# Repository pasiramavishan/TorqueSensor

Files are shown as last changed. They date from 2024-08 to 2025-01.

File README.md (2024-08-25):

# Torque-Sensor

## Power Supply

In our battery-powered setup, we utilize a regulator circuit to maintain stable voltage output, ensuring consistent power supply to both the microcontroller and strain gauges. We selected BD450M5 due to its low dropout voltage, which is typically 0.2V. Its maximum current rating is 0.5A.

<p align="center">
  Power
</p>

## Bridge Balancing Circuit
 
The initial unbalances in strain gauge circuits, caused by irregularities in gauge resistances, often exceed the actual strain-induced signal. The solution involves adjusting resistances within the Wheatstone Bridge configuration. However, manual methods pose challenges such as determining the arm needing adjustment and avoiding further imbalance.

<p align="center">
  Power
</p>

We choosed AD5171 as the digital potentiometer to adjust resistance because,
 - Stores the resistance value, maintaining the wiper position even when power is off and resuming it when power is restored.
 - Permanently stores a chosen resistance value after OTP activation.
 - Allows unlimited adjustments to the resistor value prior to OTP activation.
 - 64 The AD5171 has 64 discrete wiper positions.
 - This fine adjustment allows for precise control over the resistance settings.

 ## Instrumentation Amplifier Circuit
 
To enhance the output signal from a Wheatstone bridge, we employ an instrumentation amplifier, known for its precision in measurement applications. Specifically, we’ve chosen the AD8293G160 for its cost effectiveness and capability to amplify the signal without introducing significant noise. This amplifier maintains accuracy over time and operates efficiently with minimal power requirements. In addition, we have refined the signal further by incorporating filters to eliminate unwanted noise, ensuring a clean and reliable output for our measurement purposes. The circuit amplifies the voltage difference between the Wheatstone bridge strain gauge. 

<p align="center">
  Power
</p>

Here why we used AD8293G160.
 - Up to 160 MHz, suitable for high-speed signal processing.
 - Typically 20 µV offset voltage and 0.3 µV/°C drift, minimizing signal processing errors.
 - Typically 140 dB CMR, effective in rejecting common-mode noise.
 - Includes overvoltage protection and thermal shutdown for reliable operation.
 - The amplifier has a gain of 160, which is suitable for our application.

## Offset Circuit for Instrumentation Amplifier
 
The combination of an instrumentation amplifier, such as the AD8293G160, with a digital-to-analog converter (DAC) like the MCP4728, offers precise offset adjustment capabilities in electronic circuits. The instrumentation amplifier serves to accurately amplify small differential signals while rejecting common-mode noise. However, in some applications, it’s necessary to introduce an offset voltage to bias the amplifier’s output to a specific level or compensate for certain system characteristics. By integrating a DAC into the circuit, engineers can dynamically adjust this offset voltage digitally. The MCP4728 provides multiple channels of analog output with high resolution, typically through an I2C interface. This allows for precise control over the offset voltage applied to the instrumentation amplifier.

<p align="center">
  Power
</p>

Here’s why we used MCP4728 over other DACs.
 - Provides up to 12-bit resolution for precise analog signal representation.
 - Designed for efficient power usage, beneficial for battery-powered applications.
 - Offers low noise, high linearity, and reliable operation in various conditions.
 - Includes on-board nonvolatile memory (EEPROM) for storing DAC codes and configuration settings

### Amplifier Circuit
 
To amplify the weak signal from the instrumentation amplifier, the circuit incorporates a secondary amplifier, the OPA336, which operates efficiently on low supply voltage and features a rail-to-rail output swing. Configured as a non-inverted amplifier with a single-pole low-pass filter, it ensures signal flexibility across different force ranges. Gain adjustments are made using the AD5171 digital potentiometer, which provides precise control with 64-step resolution for optimal signal amplification.

<p align="center">
  Power
</p>

Here are the advantages of the OPA336 operational amplifier (op-amp) compared to other typical op-amps like the LM741 and TL072.
 - Very low power consumption, ideal for battery-operated devices.
 - High speed (up to 10 MHz bandwidth) and precision with low offset voltage.
 - Low noise density and distortion, suitable for sensitive measurement.
 - Designed for efficient single-supply operation.

###  Microcontroller Circuit
 
The microcontroller is used both to display the output torque value and to act as the ADC converter. The unit converts the analog signal from the strain gauges into digital data, acting as an ADC, calculates the corresponding torque value, and controls the output signal, which may involve displaying the torque value or transmitting it to external devices. The ADC converts the analog input signal into a 10-bit digital value, providing 1024 discrete levels of representation.

<p align="center">
  Power
</p>

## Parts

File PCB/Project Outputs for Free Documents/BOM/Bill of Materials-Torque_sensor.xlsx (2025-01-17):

Comment | Description | Designator | Footprint | LibRef | Quantity
0.1uF | CAP CER 0.1UF 25V C0G/NP0 1206 | C1, C3, C7, C9, C11, C12, C15, C17, C22 | FP-C1206C-EB-MFG | CMP-1037-04186-2 | 9
12063C224JAT2A | Capacitor | C2, C4 | CAPC3216X94N | 12063C224JAT2A | 2
12065C474JAT2A | Capacitor | C5 | CAPC3216X152N | 12065C474JAT2A | 1
12063C334MAT2A | Capacitor | C6, C10, C13 | CAPC3216X127N | 12063C334MAT2A | 3
12063A4R7DAT2A | Capacitor | C8 | CAPC3216X94N | 12063A4R7DAT2A | 1
CGA5L1X7R1C106K160AC | Capacitor | C14, C16 | CAPC3216X190N | CGA5L1X7R1C106K160AC | 2
12063A220JAT2A | Capacitor | C18, C19 | CAPC3216X94N | 12063A220JAT2A | 2
12063C105MAT2A | Capacitor | C20 | CAPC3216X178N | 12063C105MAT2A | 1
12063D226MAT2A | Capacitor | C21 | CAPC3216X229N | 12063D226MAT2A | 1
OPA336NA_3K | Integrated Circuit | IC1 | SOT95P280X145-5N | OPA336NA_3K | 1
BD450M5FP-CE2 | Integrated Circuit | IC2 | ROHM_TO-252-3 | BD450M5FP-CE2 | 1
MCP4728-E_UN | Integrated Circuit | IC3 | SOP50P490X110-10N | MCP4728-E_UN | 1
B4B-XH-A(LF)(SN) | CONN HEADER VERT 4POS 2.5MM | J1, J4 | FP-B4B-XH-A_LF_SN-MFG | CMP-17439-000250-1 | 2
M20-9990246 | CONN HEADER VERT 2POS 2.54MM | J2, J3 | FP-M20-9990246-MFG | CMP-15831-000009-1 | 2
87914-0606 | Connector | J5 | HDRV6W69P254_2X3_762X498X859P | 87914-0606 | 1
B2B-XH-A(LF)(SN) | CONN HEADER VERT 2POS 2.5MM | J6 | FP-B2B-XH-A_LF_SN-MFG | CMP-2000-05888-3 | 1
B3B-XH-A(LF)(SN) | CONN HEADER VERT 3POS 2.5MM | J7 | FP-B3B-XH-A_LF_SN-MFG | CMP-17439-000014-3 | 1
ERA-8AEB103V | Resistor | R1, R3, R6, R7, R9 | RESC3216X70N | ERA-8AEB103V | 5
CHP1206AFX-4701ELF | Resistor | R2, R4 | RESC3116X65N | CHP1206AFX-4701ELF | 2
ERA8AEB102V | Resistor | R5 | RESC3216X70N | ERA8AEB102V | 1
ERA-8AEB272V | Resistor | R8 | RESC3216X70N | ERA-8AEB272V | 1
TS-1187A-B-A-B | Switch | S1 | TS1187ABAB | TS-1187A-B-A-B | 1
AD5171BRJZ100-R2 | AD5171BRJZ100-R2 Digital Potentiometer 64POS 100kOhm Single Automotive 8-Pin SOT-23 T/R | U1, U3 | FP-RJ-8-IPC_A | CMP-00026-00446399-1 | 2
AD8293G160ARJZ-R7 | IC INST AMP 1 CIRCUIT SOT23-8 | U2 | FP-RJ-8-IPC_B | CMP-09116-000116-1 | 1
ATmega328P-AU | 8-bit AVR Microcontroller, 32KB Flash, 1KB EEPROM, 2KB SRAM, 32-pin TQFP, Industrial Grade (-40°C to 85°C) | U4 | 32A_M | CMP-0095-00269-2 | 1
CX3225SA40000D0PTWCC | Crystal or Oscillator | Y1 | CX3225SA40000D0PTWCC | CX3225SA40000D0PTWCC | 1

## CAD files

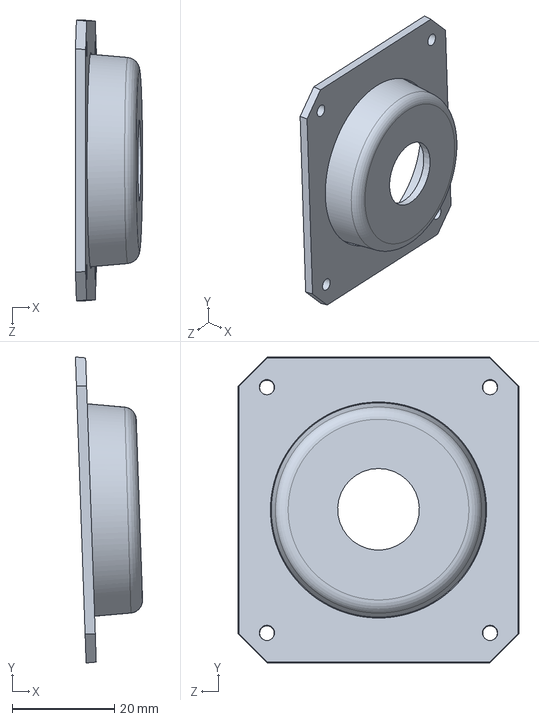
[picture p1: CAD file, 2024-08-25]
Enclosure/Side_Part.SLDPRT
13.2 x 60.0 x 55.0 mm

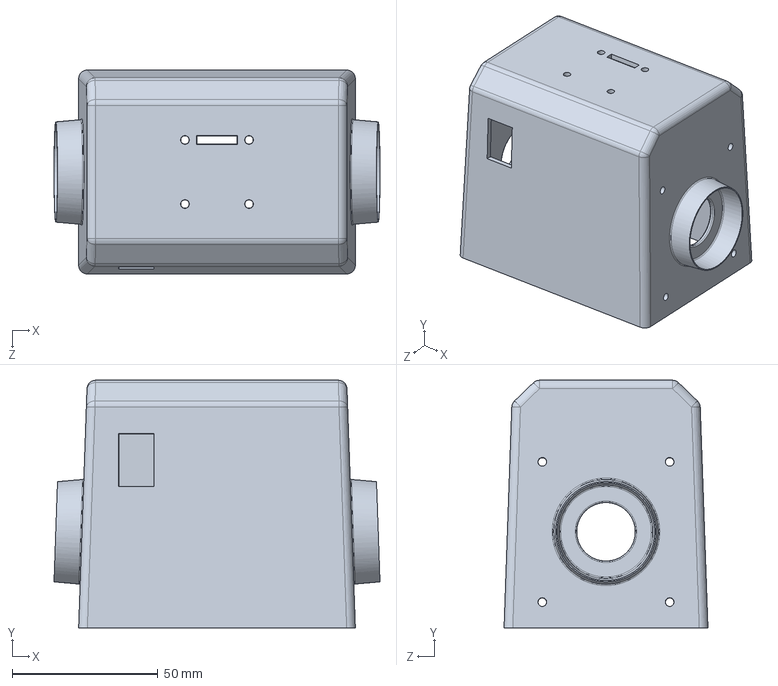
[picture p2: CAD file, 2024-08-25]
Enclosure/Top_Part.SLDPRT
111.9 x 85.0 x 70.0 mm

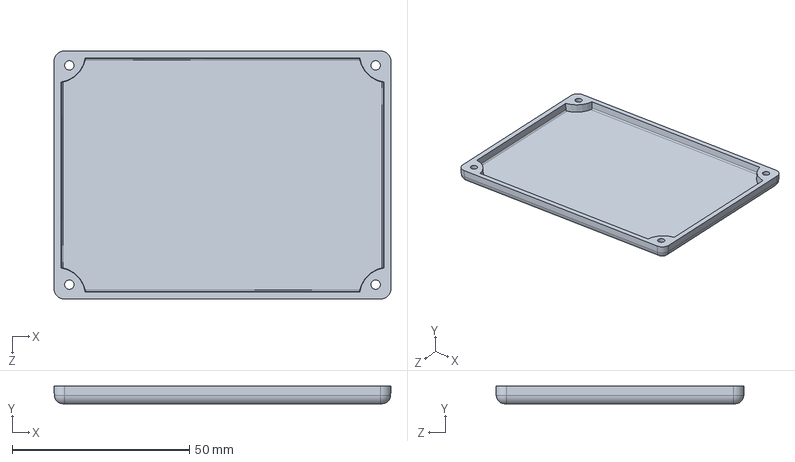
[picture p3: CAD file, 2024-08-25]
Enclosure/Bottom_Part.SLDPRT
95.0 x 5.00 x 70.0 mm

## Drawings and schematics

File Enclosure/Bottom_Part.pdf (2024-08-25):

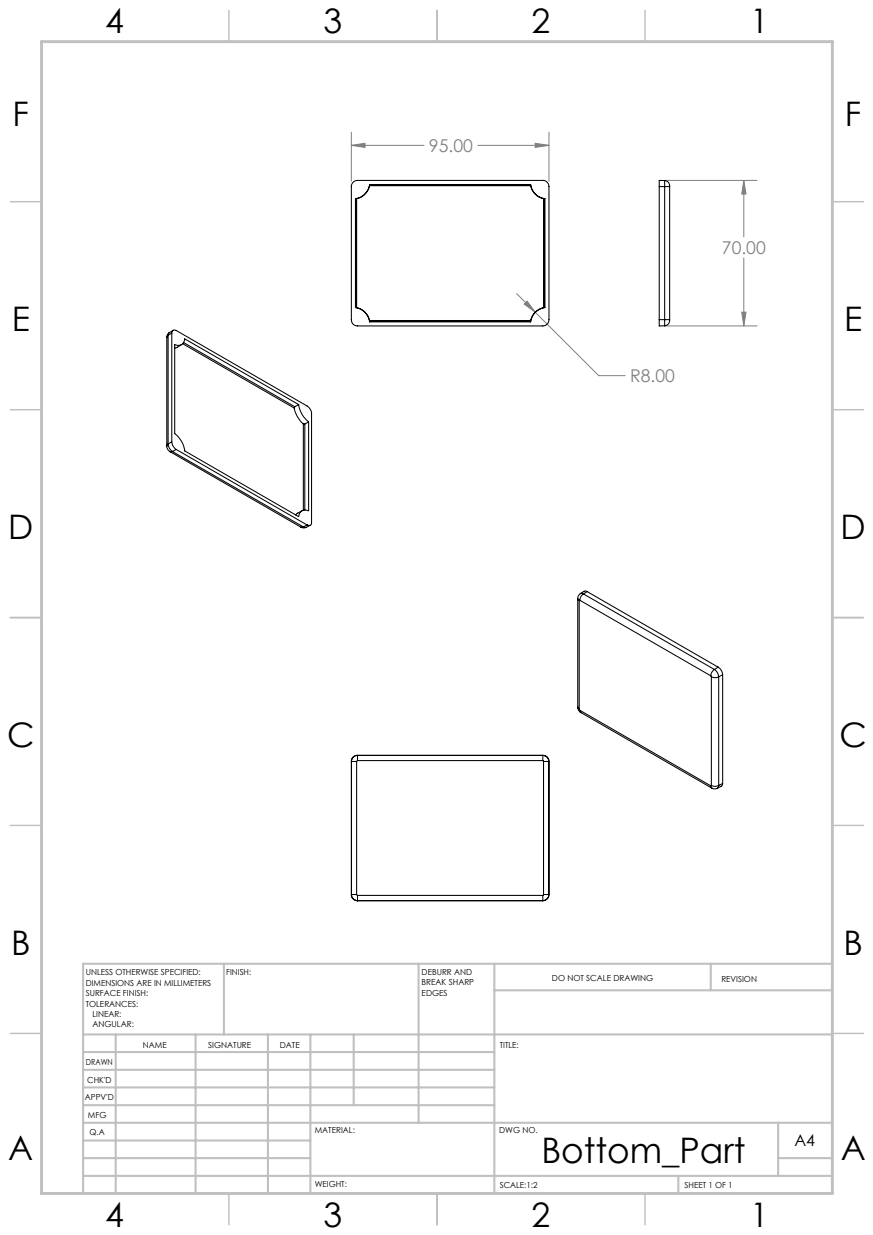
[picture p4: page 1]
FINISH:; DEBURR AND; BREAK SHARP; DO NOT SCALE DRAWING; REVISION; SCALE:1:2; SHEET 1 OF 1

UNLESS OTHERWISE SPECIFIED:
DIMENSIONS ARE IN MILLIMETERS
SURFACE FINISH:
TOLERANCES:
LINEAR:
ANGULAR:

NAME | SIGNATURE | DATE | | | | TITLE:

DRAWN
CHK'D
APPV'D
MFG
Q.A | | | | MATERIAL: | DWG NO. Bottom_Part | A4

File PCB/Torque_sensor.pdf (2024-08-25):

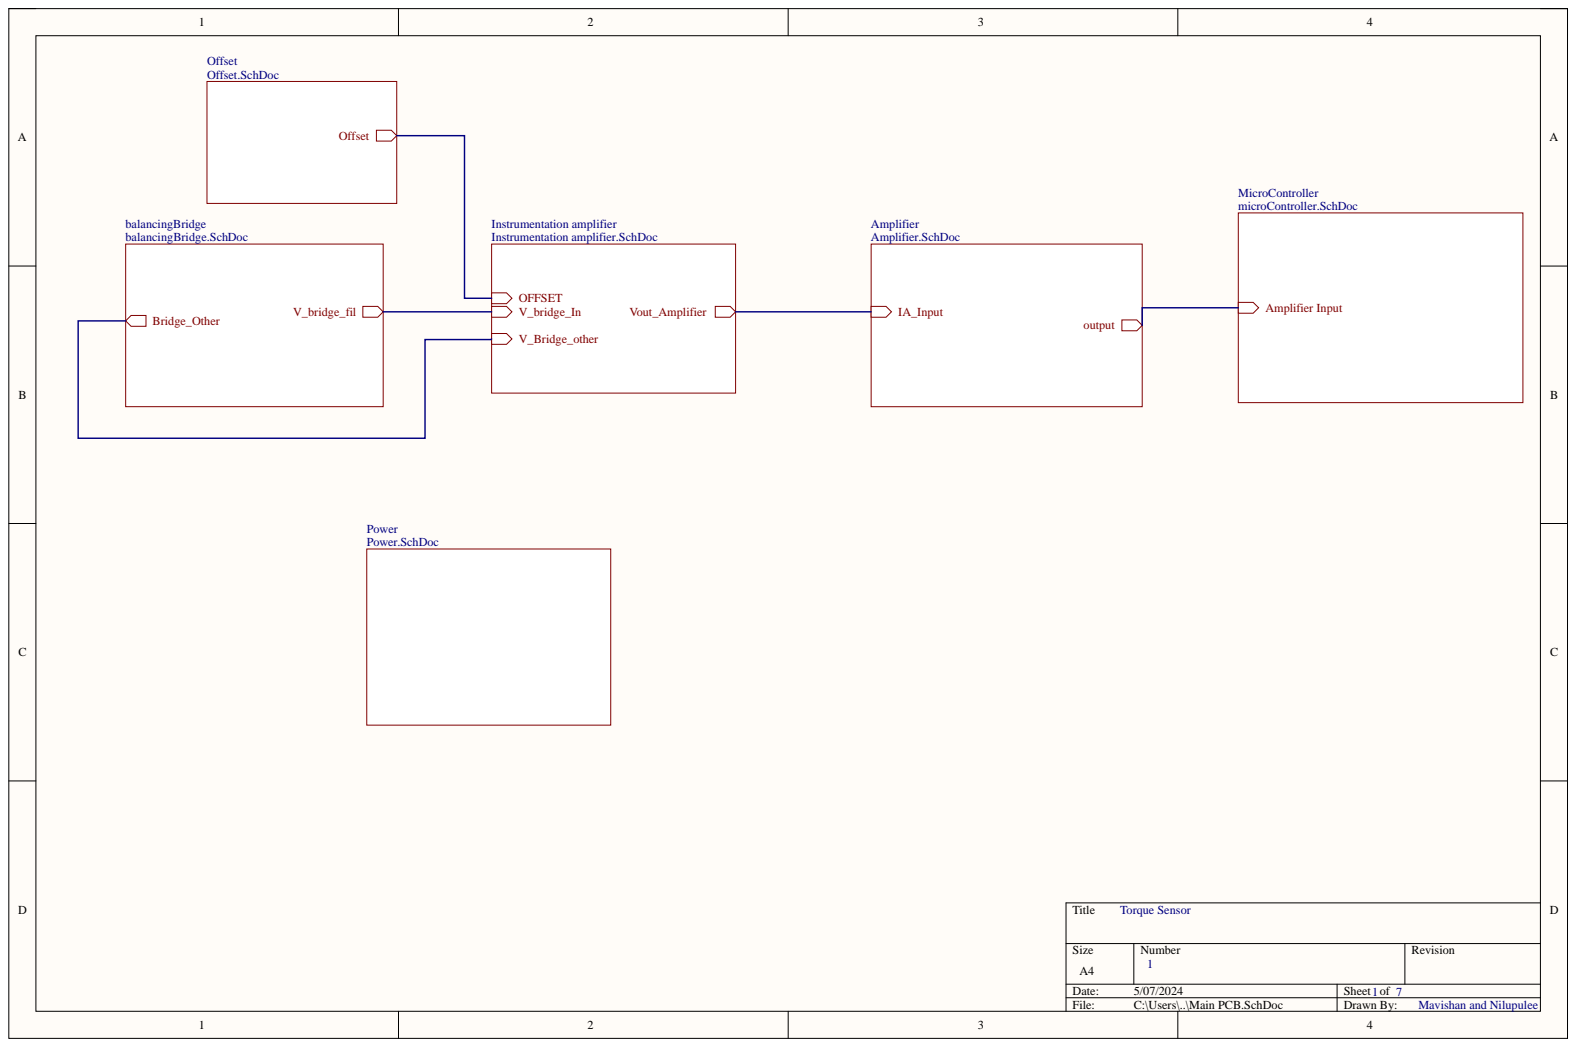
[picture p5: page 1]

Size A4 | Number 1 | Revision

Date: 5/07/2024 | Sheet of 1 7
File: C:\Users\..\Main PCB.SchDoc | Drawn By: Mavishan and Nilupulee

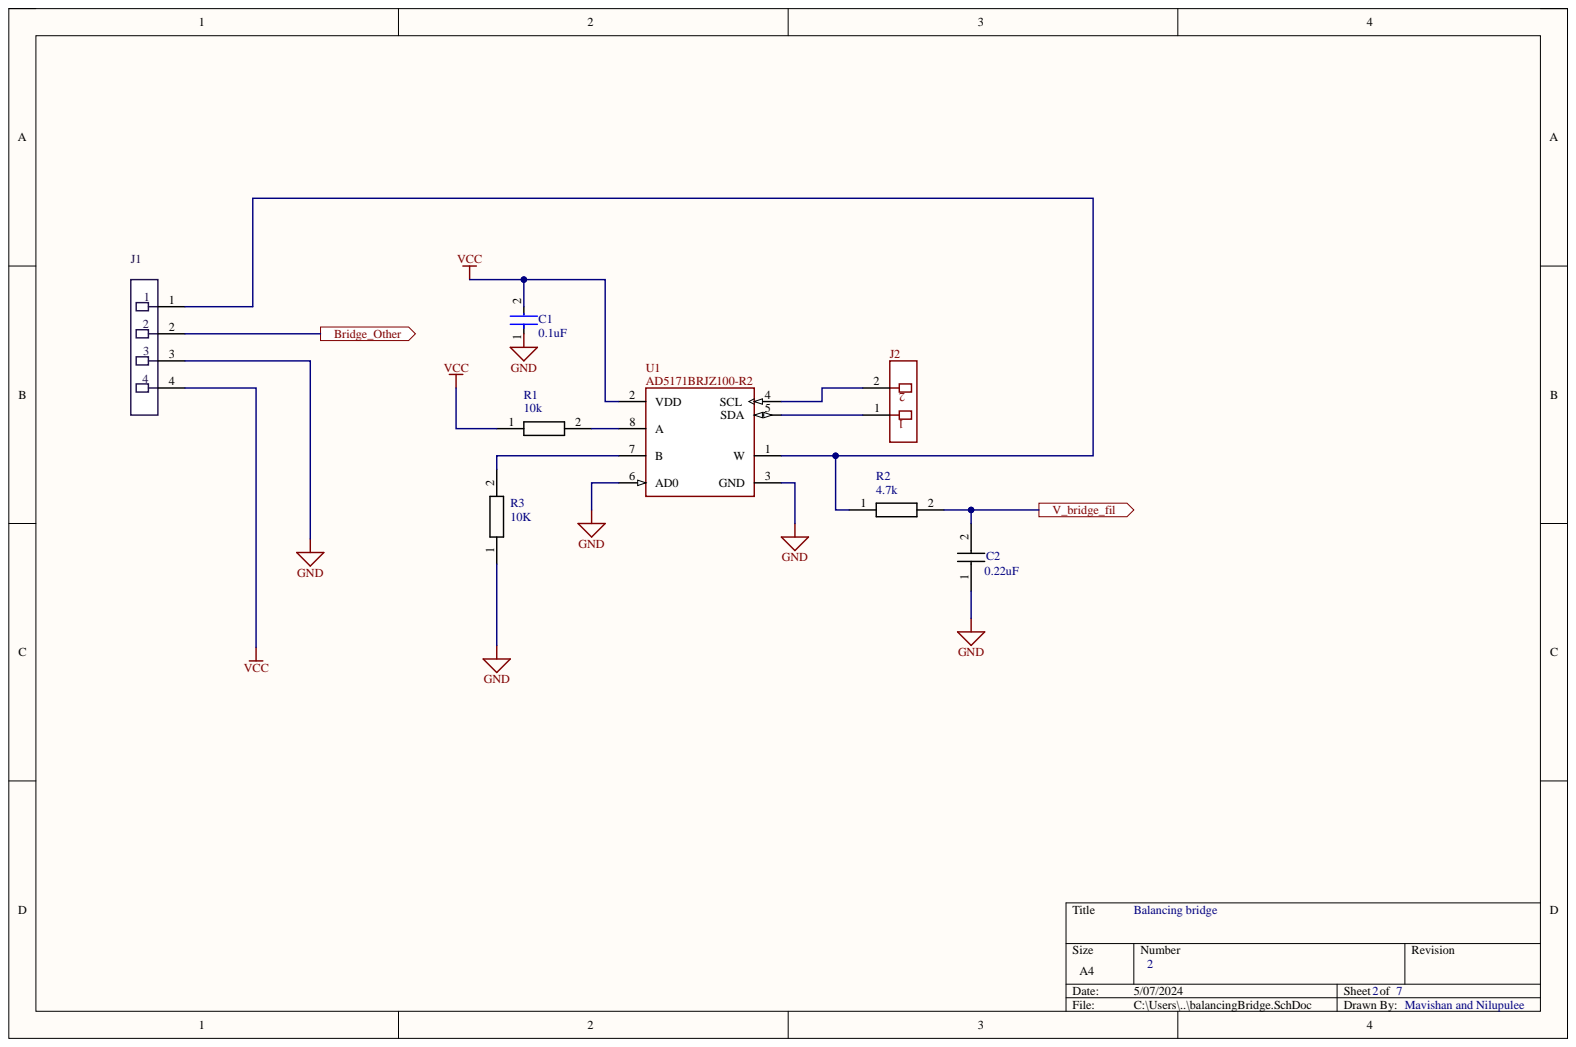
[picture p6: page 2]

GND | C1

Size A 4 | Numbe r 2 | Revision

Date: 5/07/2024 | Sheet of 2 7
File: C:\Users\..\balancingBridge. S chDoc | Drawn By: Mavishan and Nilupulee

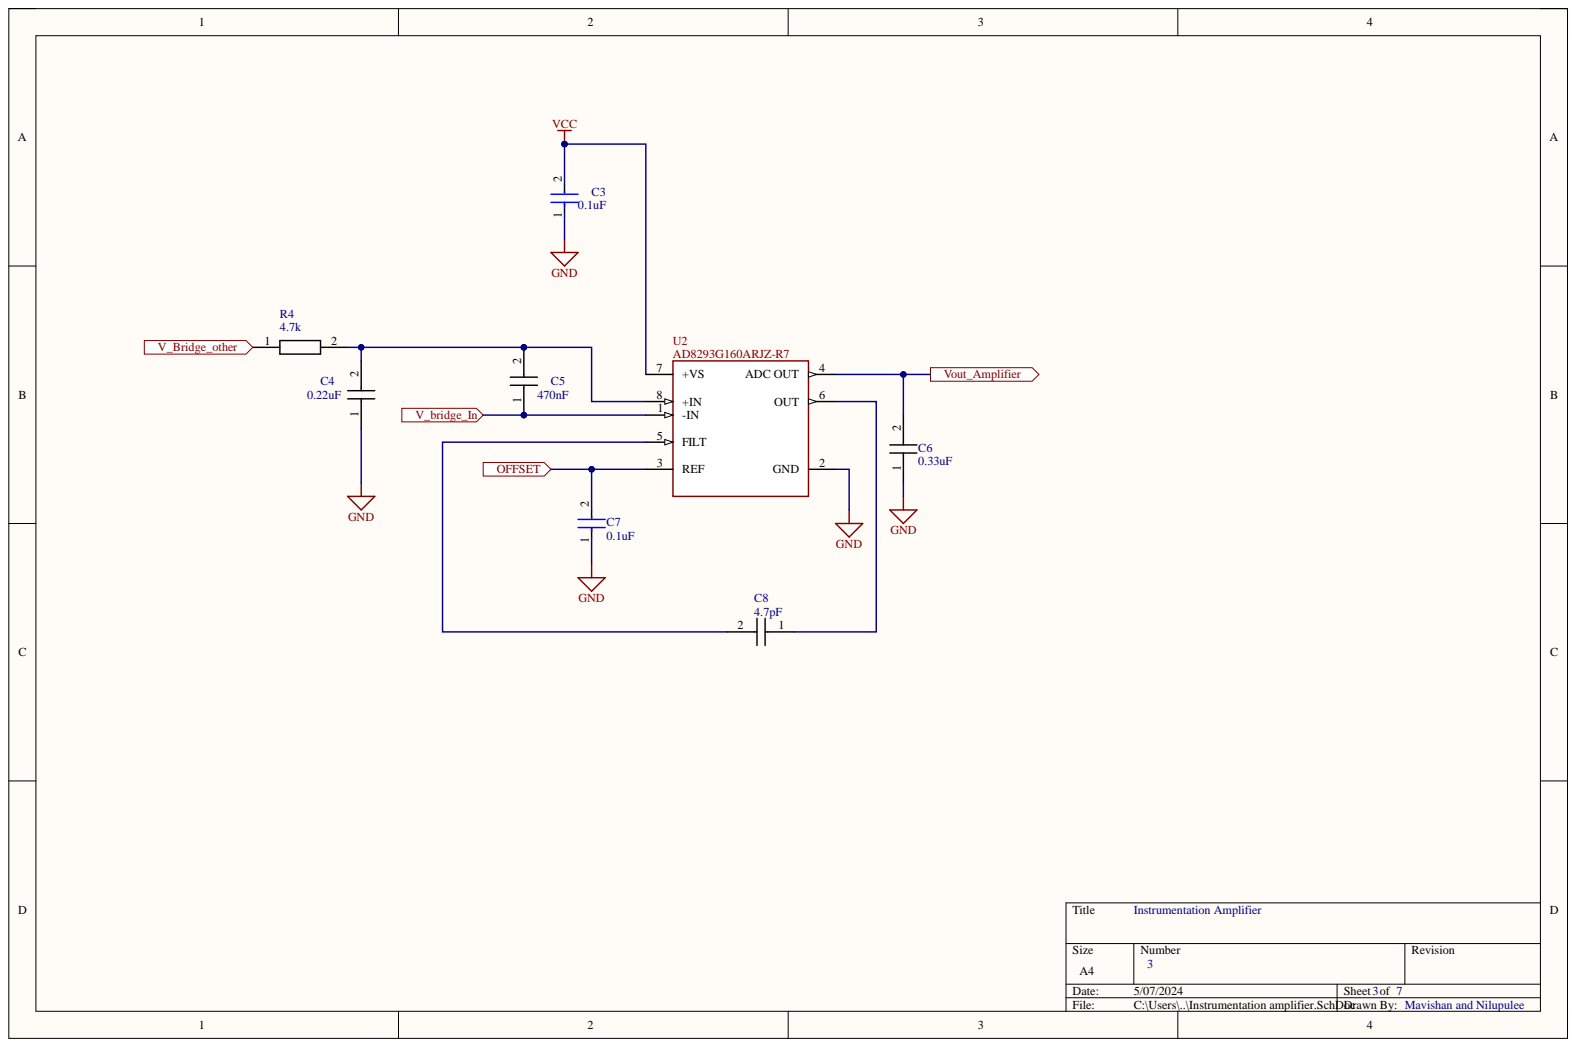
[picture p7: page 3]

Size A4 | Number 3 | Revision

Date: 5/07/2024 | Sheet of 3 7
File: C:\Users\..\Instrumentation amplifier.SchDocDrawn By: | Mavishan and Nilupulee

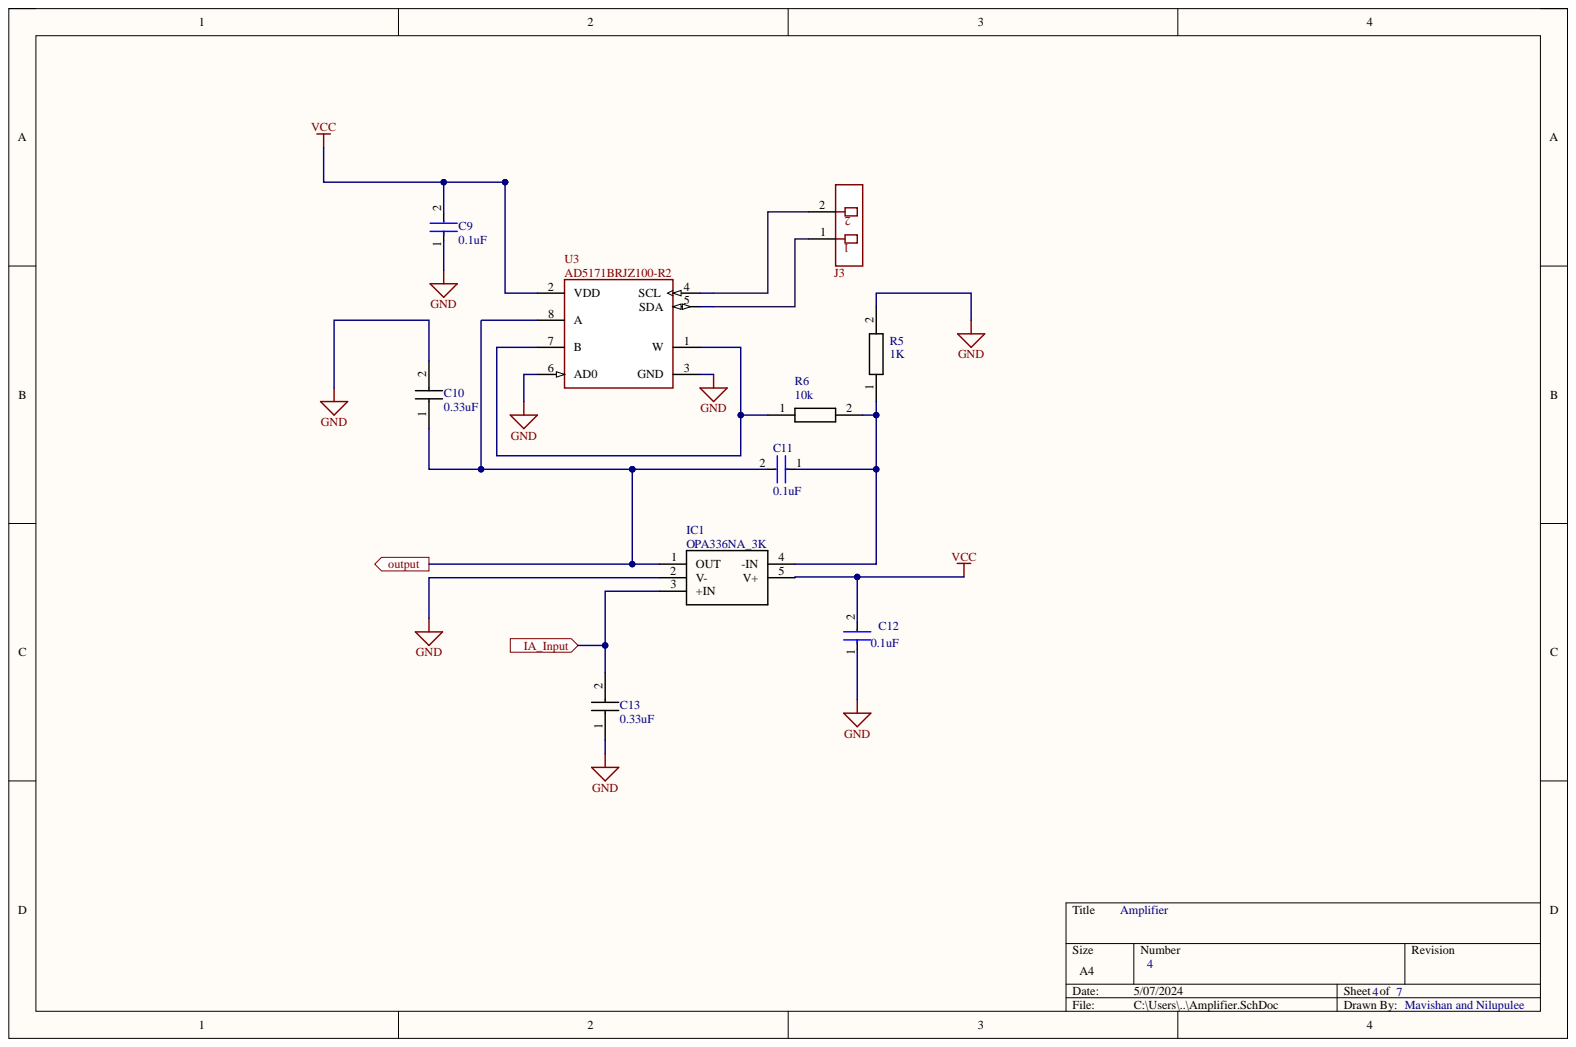
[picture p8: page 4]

Size A4 | Number 4 | Revision

Date: 5/07/2024 | Sheet of 4 7
File: C:\Users\..\Amplifier.SchDoc | Drawn By: Mavishan and Nilupulee

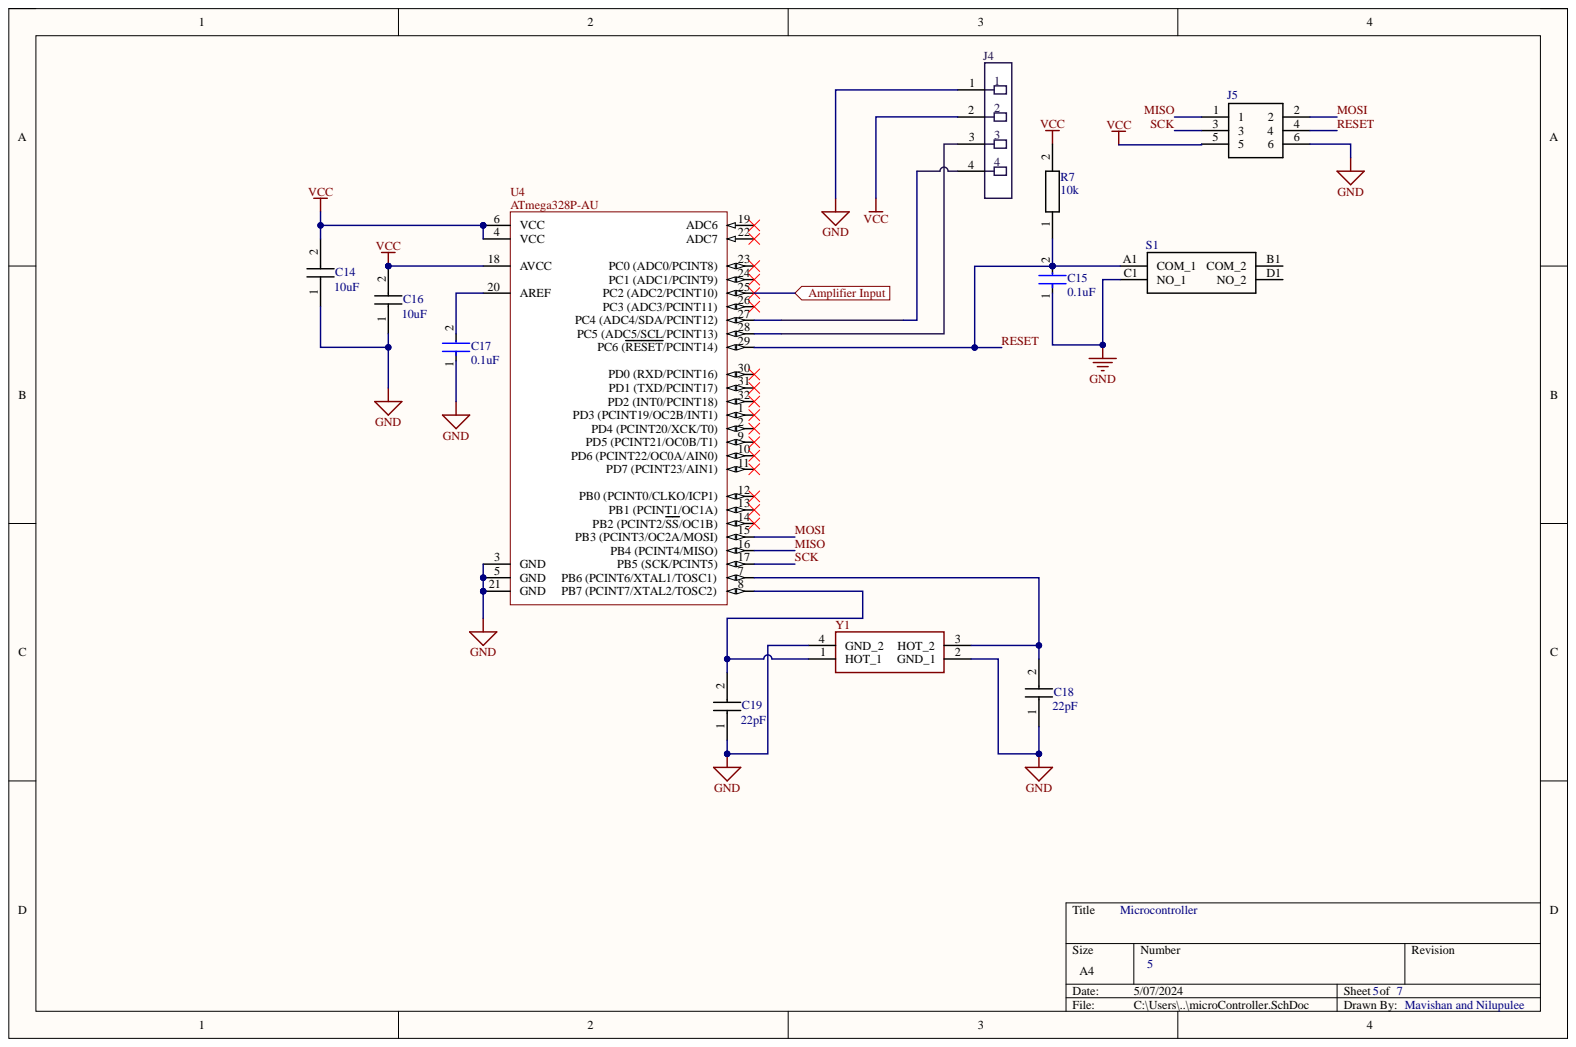
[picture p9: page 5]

Size A 4 | Numbe r 5 | Revision

Date: 5/07/2024 | Sheet of 5 7
File: C:\Users\..\microController.SchDoc | Drawn By: Mavishan and Nilupulee

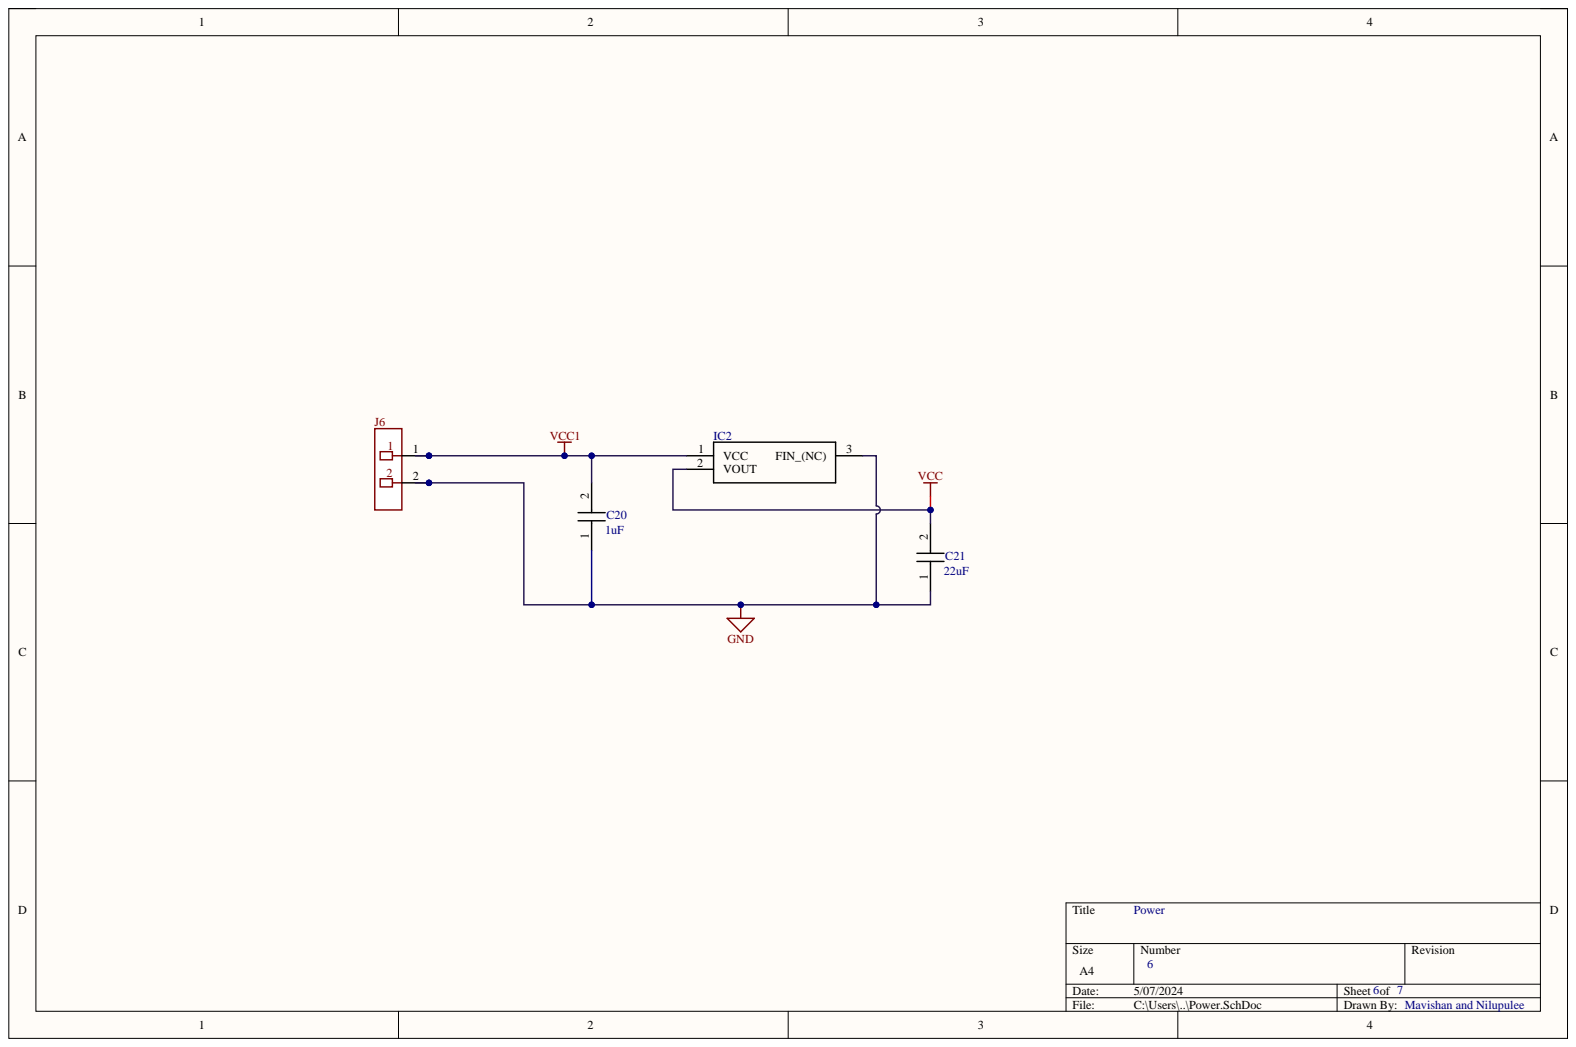
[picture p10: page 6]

Size A 4 | Numbe r 6 | Revision

Date: 5/07/2024 | Sheet of 6 7
File: C:\Users\..\Power.SchDoc | Drawn By: Mavishan and Nilupulee

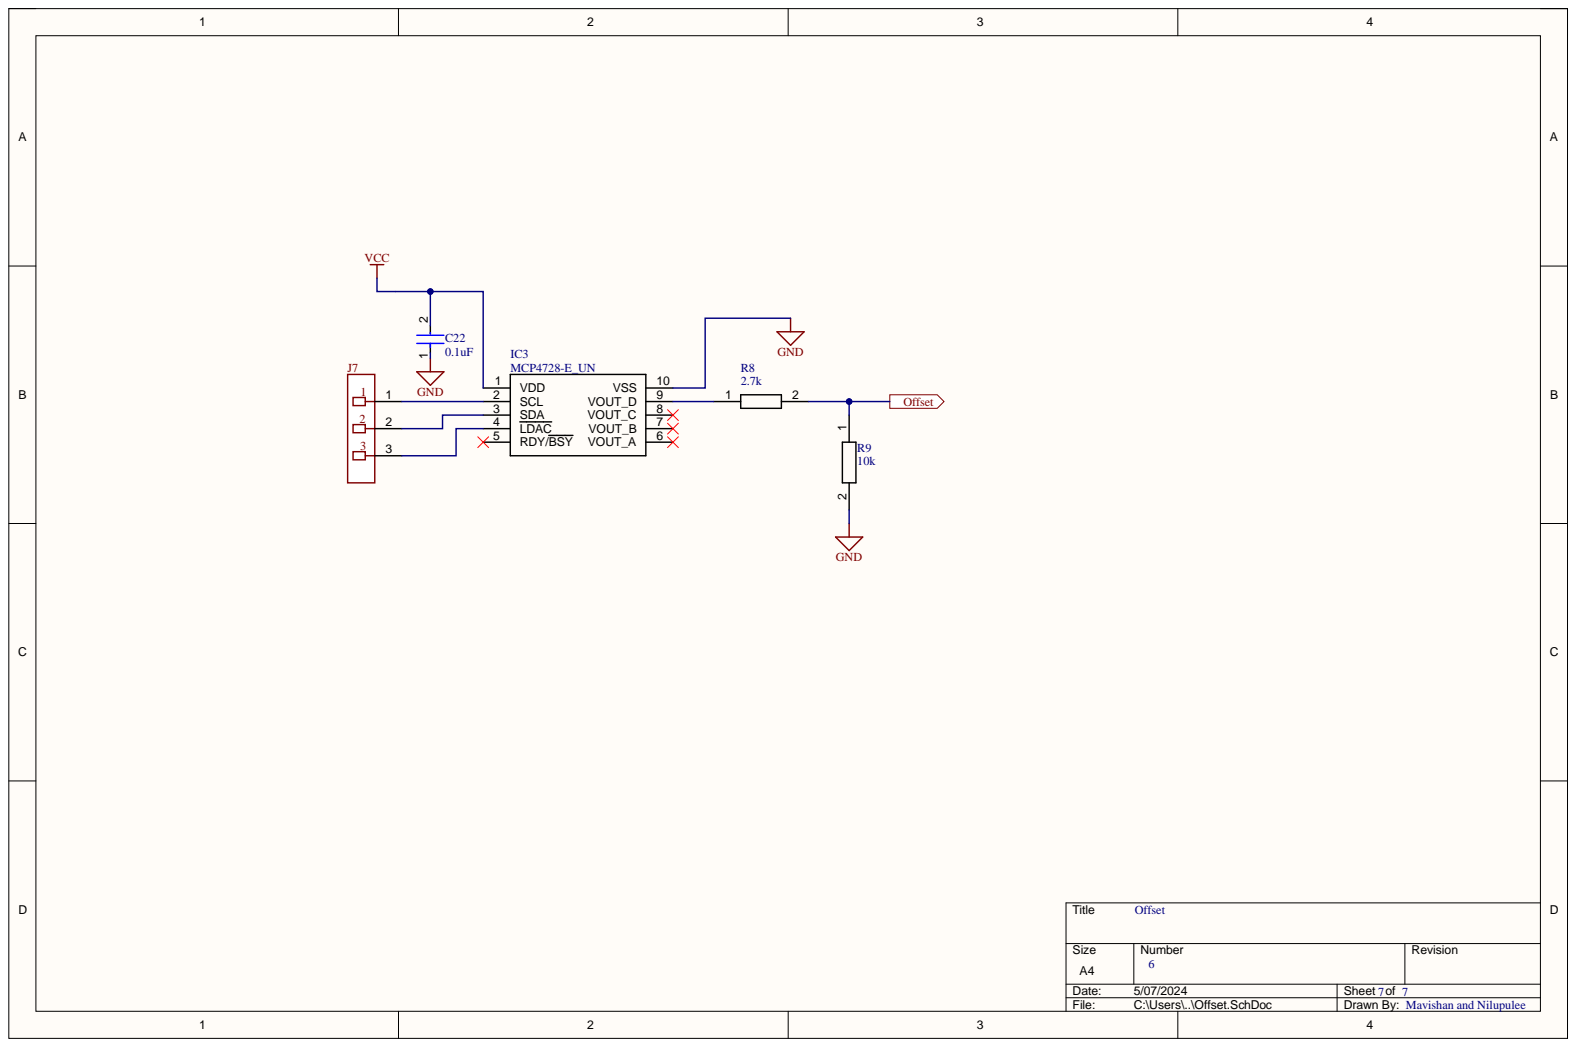
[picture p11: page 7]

Size A4 | Numbe r 6 | Revisio n

Date: 5/07/2024 | Sheet of 7 7
File: C:\Users\..\Offset.Sch D o c | Drawn By: Mavishan and Nilupulee

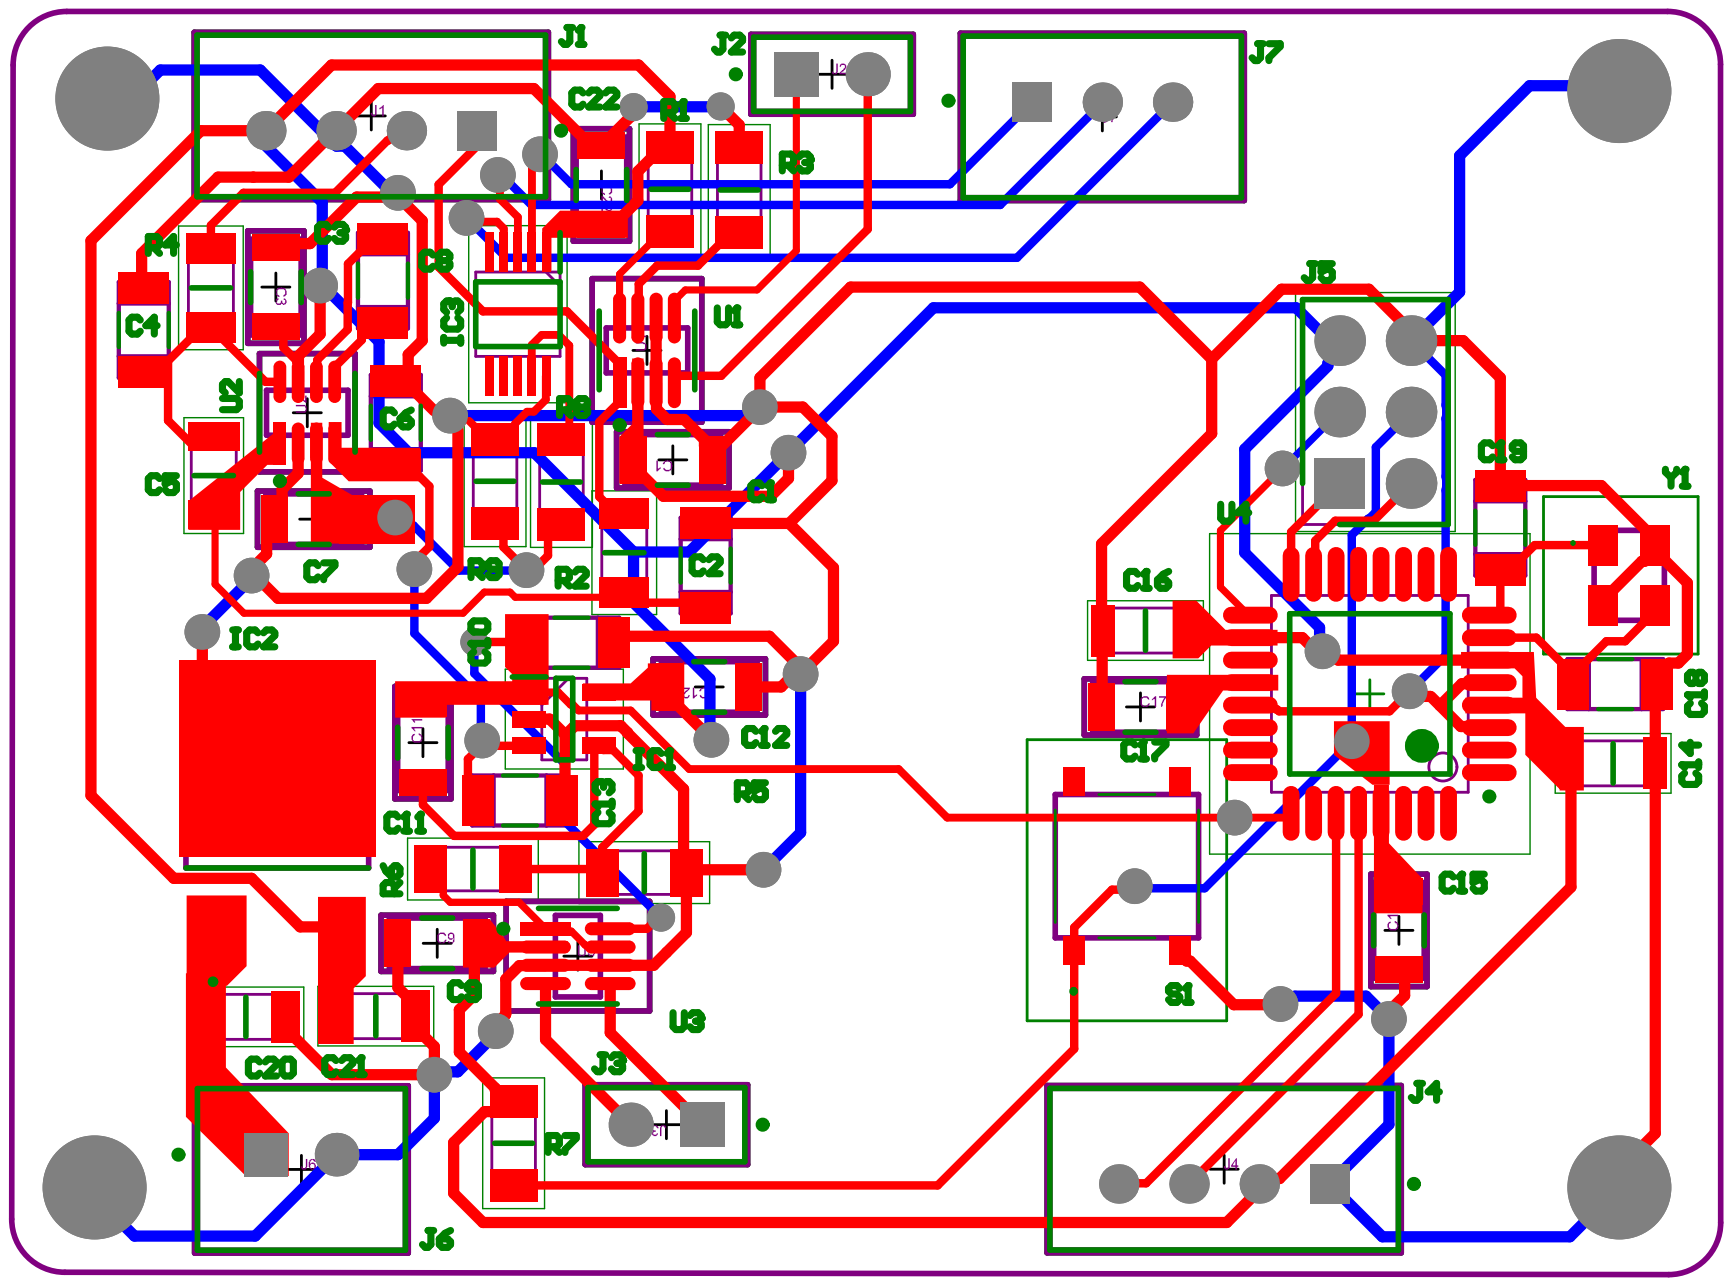
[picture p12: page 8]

Comment | Description | Designator | Footprint | LibRef | Quantity
0.1uF | CAPCER0.1UF25V C0G/NP01206 | C1, C3, C7, C9, C11, C12, C15, C17, C22 | FP-C1206C-EB-MFG | CMP-1037-04186-2 | 9
12063C224JAT2A | Capacitor | C2, C4 | CAPC3216X94N | 12063C224JAT2A | 2
12065C474JAT2A | Capacitor | C5 | CAPC3216X152N | 12065C474JAT2A | 1
12063C334MAT2A | Capacitor | C6, C10, C13 | CAPC3216X127N | 12063C334MAT2A | 3
12063A4R7DAT2A | Capacitor | C8 | CAPC3216X94N | 12063A4R7DAT2A | 1
CGA5L1X7R1C106K16 0AC | Capacitor | C14, C16 | CAPC3216X190N | CGA5L1X7R1C106K16 0AC | 2
12063A220JAT2A | Capacitor | C18, C19 | CAPC3216X94N | 12063A220JAT2A | 2
12063C105MAT2A | Capacitor | C20 | CAPC3216X178N | 12063C105MAT2A | 1
12063D226MAT2A | Capacitor | C21 | CAPC3216X229N | 12063D226MAT2A | 1
OPA336NA_3K | IntegratedCircuit | IC1 | SOT95P280X145-5N | OPA336NA_3K | 1
BD450M5FP-CE2 | IntegratedCircuit | IC2 | ROHM_TO-252-3 | BD450M5FP-CE2 | 1
MCP4728-E_UN | IntegratedCircuit | IC3 | SOP50P490X110-10N | MCP4728-E_UN | 1
B4B-XH-A(LF)(SN) | CONNHEADERVERT 4POS2.5MM | J1, J4 | FP-B4B-XH-A_LF_SN-MFG | CMP-17439-000250-1 | 2
M20-9990246 | CONNHEADERVERT 2POS2.54MM | J2, J3 | FP-M20-9990246-MFG CMP-15831-000009-1 | | 2
87914-0606 | Connector | J5 | HDRV6W69P254_2X3_ 762X498X859P | 87914-0606 | 1
B2B-XH-A(LF)(SN) | CONNHEADERVERT 2POS2.5MM | J6 | FP-B2B-XH-A_LF_SN-MFG | CMP-2000-05888-3 | 1
B3B-XH-A(LF)(SN) | CONNHEADERVERT 3POS2.5MM | J7 | FP-B3B-XH-A_LF_SN-MFG | CMP-17439-000014-3 | 1
ERA-8AEB103V | Resistor | R1, R3, R6, R7, R9 | RESC3216X70N | ERA-8AEB103V | 5
CHP1206AFX-4701ELF | Resistor | R2, R4 | RESC3116X65N | CHP1206AFX-4701ELF | 2
ERA8AEB102V | Resistor | R5 | RESC3216X70N | ERA8AEB102V | 1
ERA-8AEB272V | Resistor | R8 | RESC3216X70N | ERA-8AEB272V | 1
TS-1187A-B-A-B | Switch | S1 | TS1187ABAB | TS-1187A-B-A-B | 1
AD5171BRJZ100-R2 | AD5171BRJZ100-R2 Digital Potentiometer 64POS100kOhm SingleAutomotive8-PinSOT-23T/R | U1, U3 | FP-RJ-8-IPC_A | CMP-00026-00446399-1 | 2
AD8293G160ARJZ-R7 | ICINSTAMP1CIRCUIT SOT23-8 | U2 | FP-RJ-8-IPC_B | CMP-09116-000116-1 | 1
ATmega328P-AU | 8-bit AVR Microcontroller, 32KB Flash, 1KBEEPROM, 2KBSRAM, 32-pin TQFP, Industrial Grade (-40°Cto85°C) | U4 | 32A_M | CMP-0095-00269-2 | 1
CX3225SA40000D0PT WCC | Crystal or Oscillator | Y1 | CX3225SA40000D0PT WCC | CX3225SA40000D0PT WCC | 1

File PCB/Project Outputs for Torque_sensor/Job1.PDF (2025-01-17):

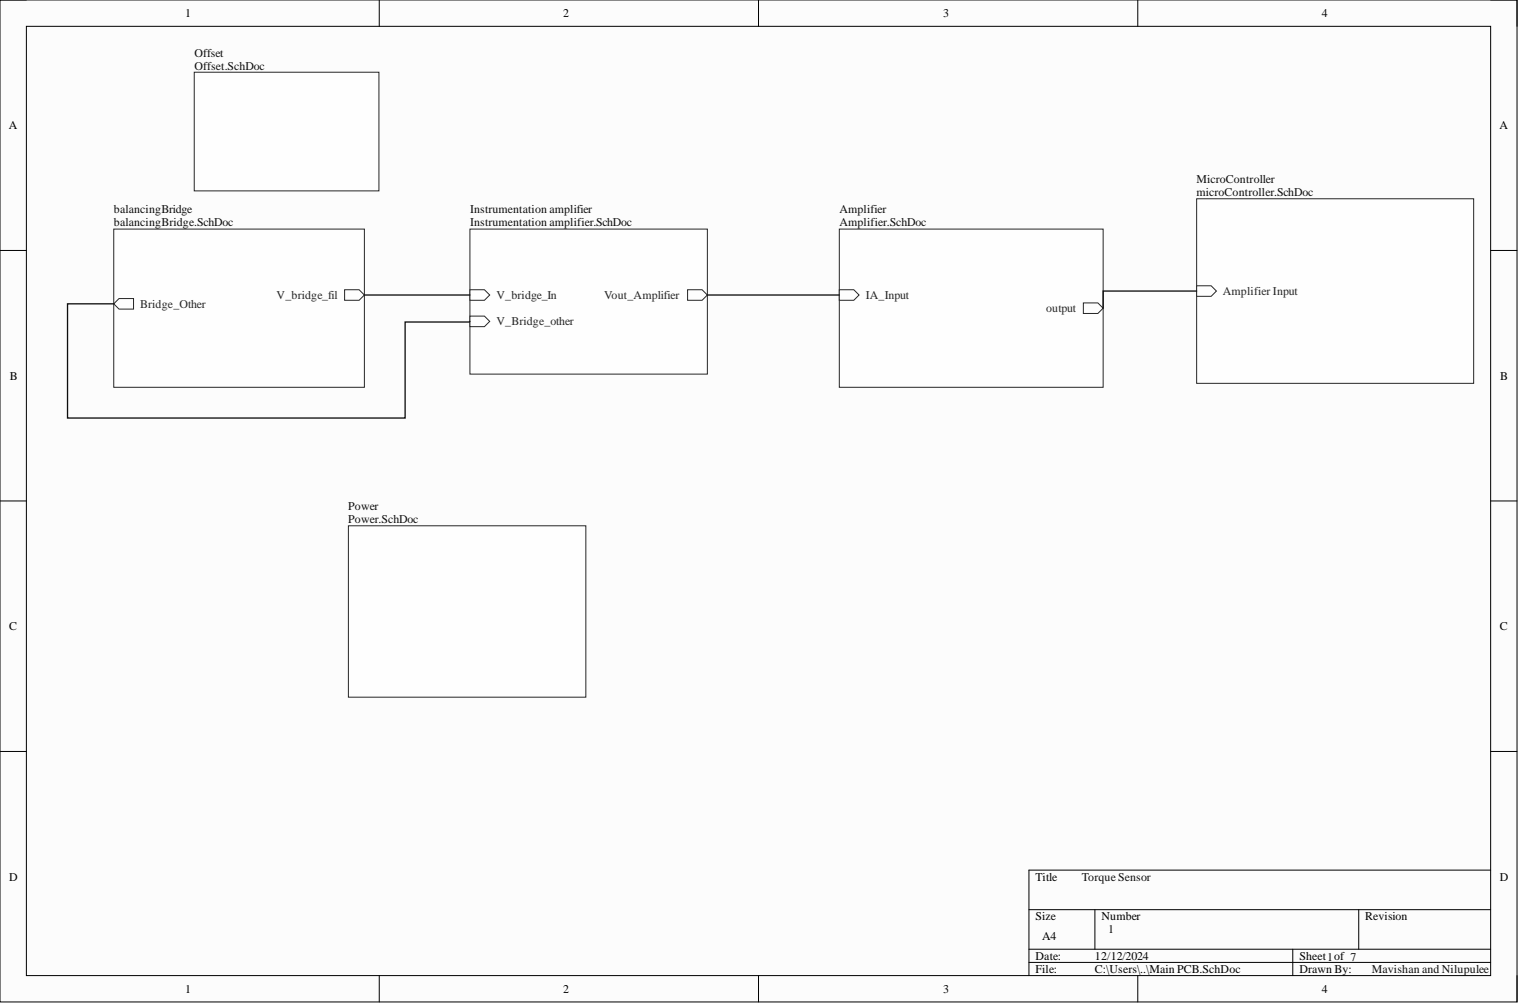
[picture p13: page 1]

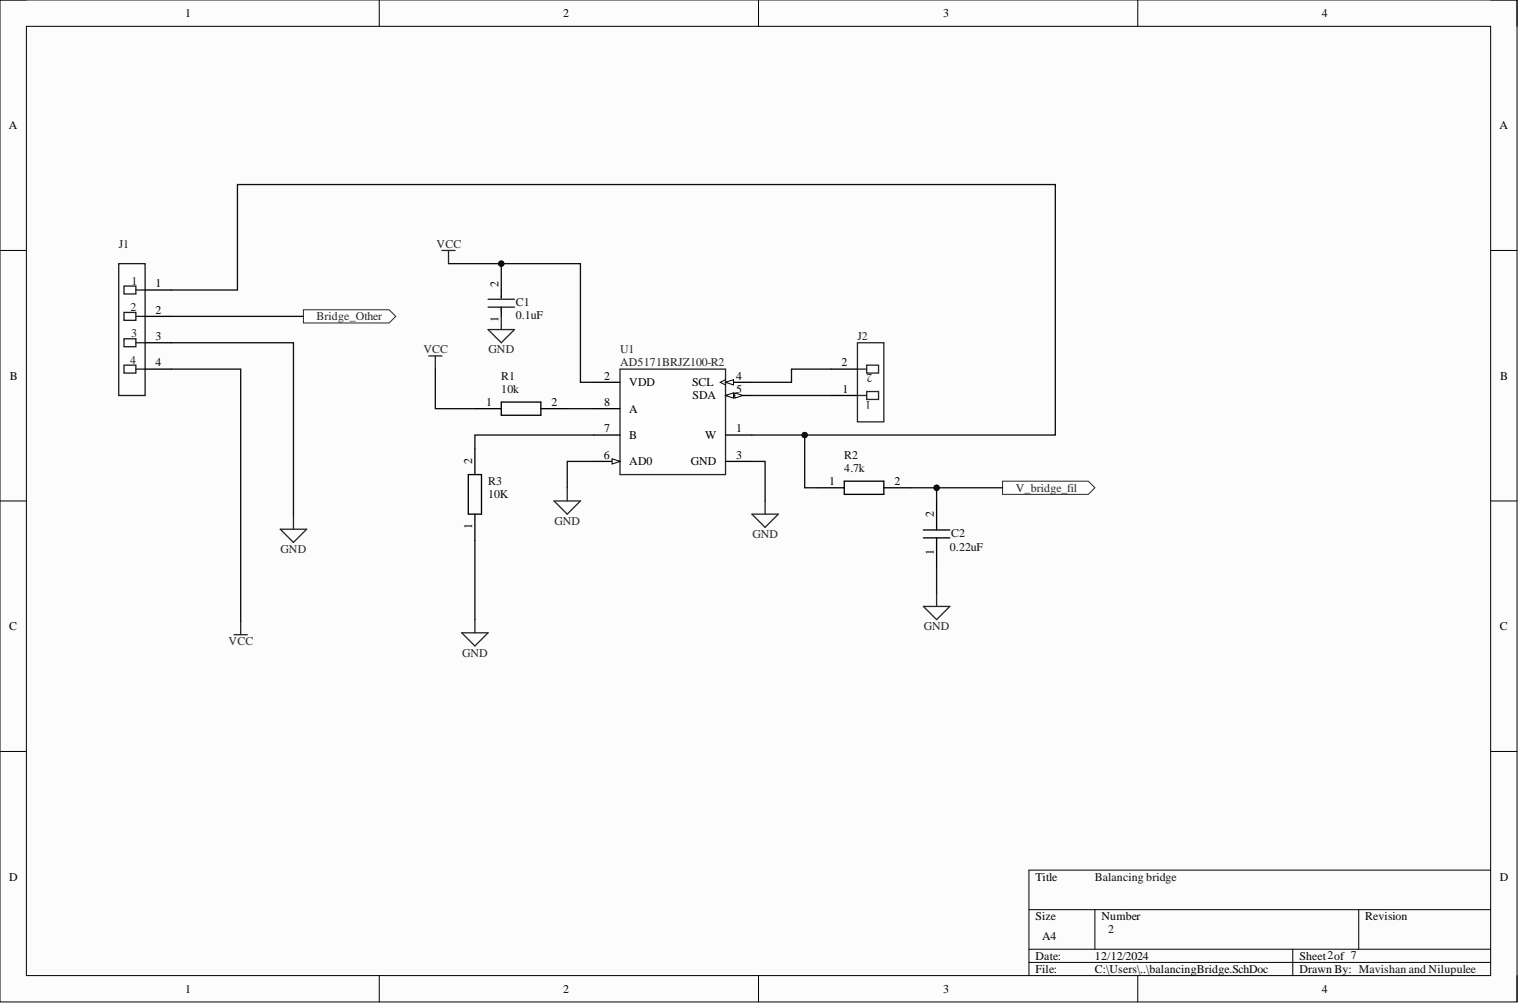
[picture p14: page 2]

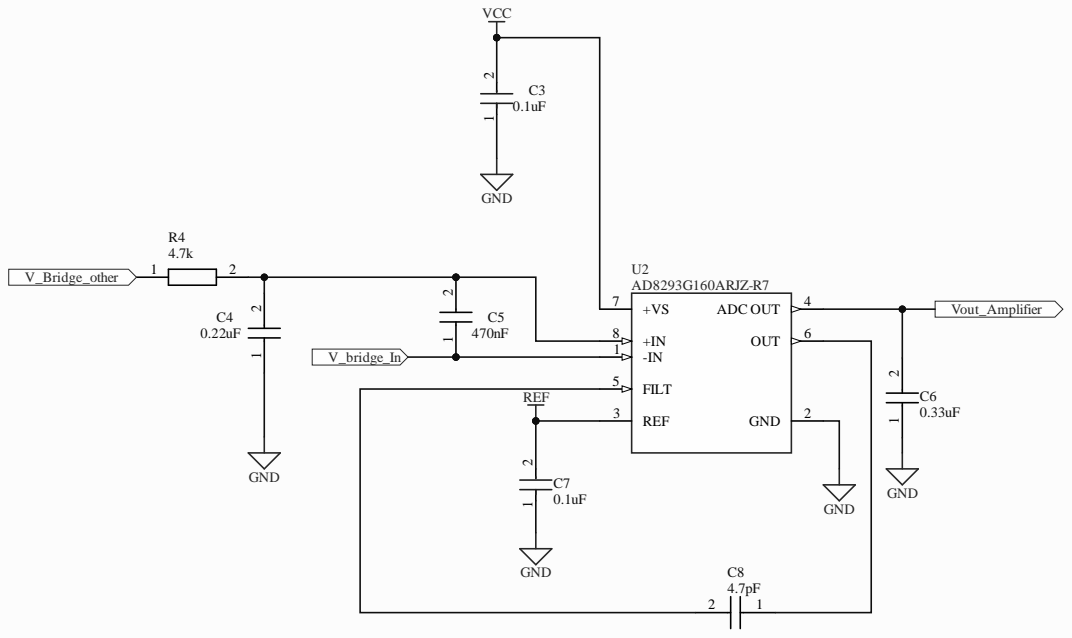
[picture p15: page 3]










Comment | Description | Designator | Footprint | LibRef | Quantity
0.1uF | CAPCER0.1UF25V C0G/NP01206 | C1, C3, C7, C9, C11, C12, C15, C17, C22 | FP-C1206C-EB-MFG | CMP-1037-04186-2 | 9
12063C224JAT2A | Capacitor | C2, C4 | CAPC3216X94N | 12063C224JAT2A | 2
12065C474JAT2A | Capacitor | C5 | CAPC3216X152N | 12065C474JAT2A | 1
12063C334MAT2A | Capacitor | C6, C10, C13 | CAPC3216X127N | 12063C334MAT2A | 3
12063A4R7DAT2A | Capacitor | C8 | CAPC3216X94N | 12063A4R7DAT2A | 1
CGA5L1X7R1C106K16 0AC | Capacitor | C14, C16 | CAPC3216X190N | CGA5L1X7R1C106K16 0AC | 2
12063A220JAT2A | Capacitor | C18, C19 | CAPC3216X94N | 12063A220JAT2A | 2
12063C105MAT2A | Capacitor | C20 | CAPC3216X178N | 12063C105MAT2A | 1
12063D226MAT2A | Capacitor | C21 | CAPC3216X229N | 12063D226MAT2A | 1
OPA336NA_3K | IntegratedCircuit | IC1 | SOT95P280X145-5N | OPA336NA_3K | 1
BD450M5FP-CE2 | IntegratedCircuit | IC2 | ROHM_TO-252-3 | BD450M5FP-CE2 | 1
MCP4728-E_UN | IntegratedCircuit | IC3 | SOP50P490X110-10N | MCP4728-E_UN | 1
B4B-XH-A(LF)(SN) | CONNHEADERVERT 4POS2.5MM | J1, J4 | FP-B4B-XH-A_LF_SN-MFG | CMP-17439-000250-1 | 2
M20-9990246 | CONNHEADERVERT 2POS2.54MM | J2, J3 | FP-M20-9990246-MFG | CMP-15831-000009-1 | 2
87914-0606 | Connector | J5 | HDRV6W69P254_2X3_ 762X498X859P | 87914-0606 | 1
B2B-XH-A(LF)(SN) | CONNHEADERVERT 2POS2.5MM | J6 | FP-B2B-XH-A_LF_SN-MFG | CMP-2000-05888-3 | 1
B3B-XH-A(LF)(SN) | CONNHEADERVERT 3POS2.5MM | J7 | FP-B3B-XH-A_LF_SN-MFG | CMP-17439-000014-3 | 1
ERA-8AEB103V | Resistor | R1, R3, R6, R7, R9 | RESC3216X70N | ERA-8AEB103V | 5
CHP1206AFX-4701ELF | Resistor | R2, R4 | RESC3116X65N | CHP1206AFX-4701ELF | 2
ERA8AEB102V | Resistor | R5 | RESC3216X70N | ERA8AEB102V | 1
ERA-8AEB272V | Resistor | R8 | RESC3216X70N | ERA-8AEB272V | 1
TS-1187A-B-A-B | Switch | S1 | TS1187ABAB | TS-1187A-B-A-B | 1
AD5171BRJZ100-R2 | AD5171BRJZ100-R2 Digital Potentiometer 64POS100kOhm SingleAutomotive8-PinSOT-23T/R | U1, U3 | FP-RJ-8-IPC_A | CMP-00026-00446399-1 | 2
AD8293G160ARJZ-R7 | ICINSTAMP1CIRCUIT SOT23-8 | U2 | FP-RJ-8-IPC_B | CMP-09116-000116-1 | 1
ATmega328P-AU | 8-bit AVR Microcontroller, 32KB Flash, 1KBEEPROM, 2KBSRAM, 32-pin TQFP, Industrial Grade (-40°Cto85°C) | U4 | 32A_M | CMP-0095-00269-2 | 1
CX3225SA40000D0PT WCC | Crystal or Oscillator | Y1 | CX3225SA40000D0PT WCC | CX3225SA40000D0PT WCC | 1

### Electrical Rules Check Report
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

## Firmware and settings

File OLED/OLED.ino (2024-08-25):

#include <avr/io.h>
#include <util/delay.h>

#define F_CPU 16000000UL
#define display_ADDRESS 0x3C
#define display_COMMAND 0x00
#define display_DATA 0x40

#define SCL_PIN PC5
#define SDA_PIN PC4

#define READ_PIN A0

uint8_t buffer[1024];
double ox, oy;
bool Redraw4 = true;
double x = 0, y = 0;

void setup() {
    DDRC |= (1 << SCL_PIN) | (1 << SDA_PIN);

    // Initialize I2C and display
    i2c_init();
    display_init();

    ADMUX = (1 << REFS0);
    ADCSRA = (1 << ADEN) | (1 << ADPS2) | (1 << ADPS1);

    // Clear the display
    display_clear();
    display_show();
}

void loop() {
    ADCSRA |= (1 << ADSC); 
    while (ADCSRA & (1 << ADSC)); // Wait for conversion to complete
    uint16_t adc_value = ADC;

    double bvolts = adc_value;
    x += 1;

    DrawCGraph(x, bvolts, 30, 50, 75, 30, 0, 100, 25, 0, 1024, 512, 0, 
    "Bits vs Seconds", Redraw4);

    if (x > 100) {
        while (1) {}
    }

    _delay_ms(1000);
}

void i2c_init(void) {
    TWSR = 0x00; 
    TWBR = ((F_CPU / 100000UL) - 16) / 2; // Set the TWI frequency to 100kHz
}

void i2c_start(void) {
    TWCR = (1 << TWINT) | (1 << TWSTA) | (1 << TWEN); 
    while (!(TWCR & (1 << TWINT)));
}

void i2c_stop(void) {
    TWCR = (1 << TWINT) | (1 << TWSTO) | (1 << TWEN); 
    while (TWCR & (1 << TWSTO));
}

void i2c_write(uint8_t data) {
    TWDR = data;
    TWCR = (1 << TWINT) | (1 << TWEN); 
    while (!(TWCR & (1 << TWINT)));
}

void display_command(uint8_t command) {
    i2c_start();
    i2c_write(display_ADDRESS << 1);
    i2c_write(display_COMMAND);
    i2c_write(command);
    i2c_stop();
}

void display_init(void) {
    _delay_ms(100);  
    display_command(0xAE); // Display OFF
    display_command(0x20); // Set Memory Addressing Mode
    display_command(0x00); // Horizontal Addressing Mode
    display_command(0xB0); // Set Page Start Address for Page Addressing Mode
    display_command(0xC8); 
    display_command(0x00); // Set low column address
    display_command(0x10); // Set high column address
    display_command(0x40); // Set start line address
    display_command(0x81); // Set contrast control 
    display_command(0xFF); // Max contrast
    display_command(0xA1); 
    display_command(0xA6); // Set Normal Display
    display_command(0xA8); // Set Multiplex Ratio
    display_command(0x3F); 
    display_command(0xA4); // Entire Display ON, Output RAM to Display
    display_command(0xD3); // Set Display Offset
    display_command(0x00); // No offset
    display_command(0xD5); 
    display_command(0xF0); // Highest frequency
    display_command(0xD9); // Set Pre-charge Period
    display_command(0x22); // Pre-charge period
    display_command(0xDA); // Set COM Pins Hardware Configuration
    display_command(0x12);
    display_command(0xDB);
    display_command(0x20); 
    display_command(0x8D); // Set Charge Pump
    display_command(0x14);
    display_command(0xAF); // Display ON
}

void display_clear(void) {
    // Clear the display buffer
    for (int i = 0; i < 1024; i++) {
        buffer[i] = 0x00;
    }
}

void display_show(void) {
    // Send the display buffer content to the OLED display
    for (uint8_t page = 0; page < 8; page++) {
        display_command(0xB0 + page); 
        display_command(0x00);      
        display_command(0x10);        
        i2c_start();                   
        i2c_write(display_ADDRESS << 1); 
        i2c_write(display_DATA);          
        for (uint8_t col = 0; col < 128; col++) {
            i2c_write(buffer[ col ]);   // Display buffer 128
        }
        i2c_stop(); 
    }
}

void display_draw_pixel(int x, int y, bool color) {
    if (x >= 0 && x < 128 && y >= 0 && y < 64) {
        if (color) {
            buffer[x + (y / 8) * 128] |= (1 << (y % 8)); // Set pixel on
        } else {
            buffer[x + (y / 8) * 128] &= ~(1 << (y % 8)); // Set pixel off
        }
    }
}

void DrawCGraph(double x, double y, double gx, double gy, double w, double h, 
double xlo, double xhi, double xinc, double ylo, double yhi, double yinc, 
double dig, const char* title, bool& Redraw) {

    double i;
    double temp;

    if (Redraw) {
        Redraw = false;

        // Draw the title
        for (int i = 0; title[i] != '\0'; i++) {
            display_draw_pixel(i * 6, 0, 1); 
        }

        // Calculate initial display coordinates
        ox = (x - xlo) * (w) / (xhi - xlo) + gx;
        oy = (y - ylo) * (gy - h - gy) / (yhi - ylo) + gy;

        // Draw y scale
        for (i = ylo; i <= yhi; i += yinc) {
            temp = (i - ylo) * (gy - h - gy) / (yhi - ylo) + gy;
            if (i == 0) {
                for (int j = gx - 3; j < gx + w + 3; j++) {
                    display_draw_pixel(j, temp, 1); 
                }
            } else {
                for (int j = gx - 3; j < gx; j++) {
                    display_draw_pixel(j, temp, 1);
                }
            }
        }

        // Draw x scale
        for (i = xlo; i <= xhi; i += xinc) {
            temp = (i - xlo) * (w) / (xhi - xlo) + gx;
            if (i == 0) {
                for (int j = gy - h; j < gy + 3; j++) {
                    display_draw_pixel(temp, j, 1); 
                }
            } else {
                for (int j = gy; j < gy + 3; j++) {
                    display_draw_pixel(temp, j, 1);
                }
            }
        }
    }

    // Update current point and draw it on the display
    x = (x - xlo) * (w) / (xhi - xlo) + gx;
    y = (y - ylo) * (gy - h - gy) / (yhi - ylo) + gy;
    display_draw_pixel(ox, oy, 1); 
    display_draw_pixel(x, y, 1);  
    ox = x; 
    oy = y;
    display_show(); 
}

// To execute loop function continuously
int main(void) {
    setup(); 
    while (1) {
        loop(); 
    }
    return 0;
}

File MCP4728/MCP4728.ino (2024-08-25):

#include <avr/io.h>
#include <util/delay.h>

#define F_CPU 16000000UL  
#define MCP4728_ADDR 0x60 // MCP4728 I2C address

void i2c_init(void) {
  TWSR = 0x00; 
  TWBR = ((F_CPU / 100000UL) - 16) / 2; // Set the TWI frequency to 100kHz
}

void i2c_start(void) {
  TWCR = (1 << TWINT) | (1 << TWSTA) | (1 << TWEN); 
  while (!(TWCR & (1 << TWINT)));
}

void i2c_stop(void) {
  TWCR = (1 << TWINT) | (1 << TWSTO) | (1 << TWEN); 
  while (TWCR & (1 << TWSTO));
}

void i2c_write(uint8_t data) {
  TWDR = data;
  TWCR = (1 << TWINT) | (1 << TWEN); 
  while (!(TWCR & (1 << TWINT)));
}

void mcp4728_set_output(uint16_t value) {
    uint8_t buffer[3];
    buffer[0] = 0b01011110;           // Command byte for fast write to channel D
    buffer[1] = (value >> 8) & 0xFF;  // High byte of DAC value
    buffer[2] = value & 0xFF;         // Low byte of DAC value

    i2c_start();
    i2c_write(MCP4728_ADDR << 1);     // Send MCP4728 address with write bit
    for (uint8_t i = 0; i < 3; i++) {
        i2c_write(buffer[i]);         // Send control byte and DAC value bytes
    }
    i2c_stop();
}

int main(void) {
    i2c_init();    
    mcp4728_set_output(2048); // Set MCP4728 DAC output to 512

    while (1) {
        _delay_ms(1000); 
    }
    
    return 0;
}
